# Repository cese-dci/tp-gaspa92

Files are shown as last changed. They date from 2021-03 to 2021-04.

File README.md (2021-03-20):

[][cc-by-sa]

This work is licensed under a
[Creative Commons Attribution-ShareAlike 4.0 International License][cc-by-sa].

[][cc-by-sa]

[cc-by-sa]: http://creativecommons.org/licenses/by-sa/4.0/
[cc-by-sa-image]: https://licensebuttons.net/l/by-sa/4.0/88x31.png
[cc-by-sa-shield]: https://img.shields.io/badge/License-CC%20BY--SA%204.0-lightgrey.svg

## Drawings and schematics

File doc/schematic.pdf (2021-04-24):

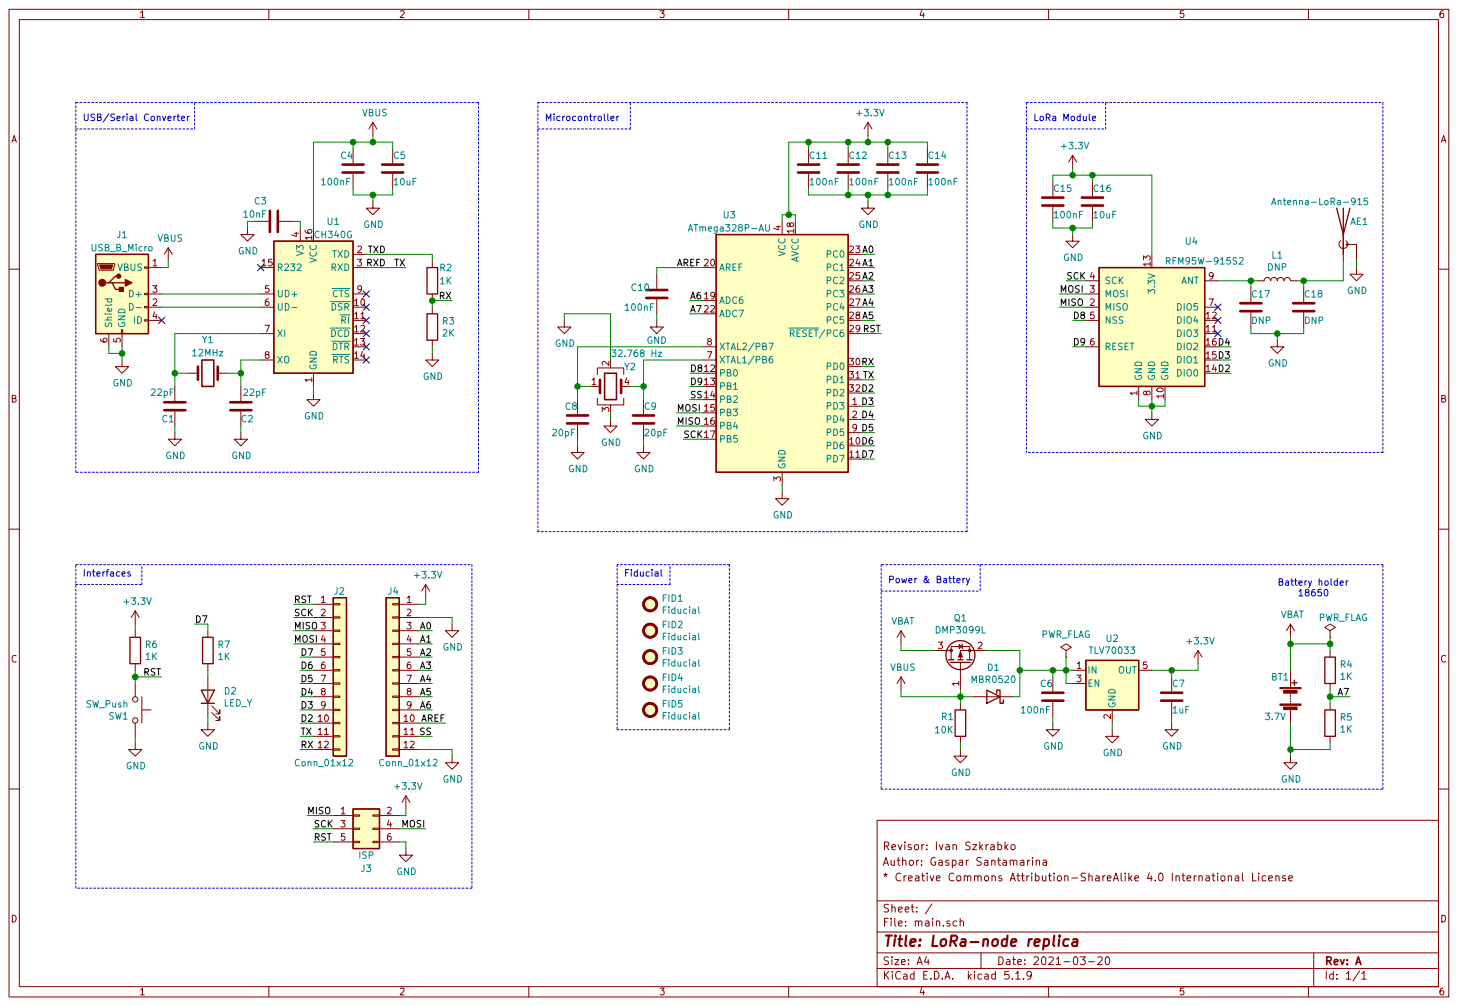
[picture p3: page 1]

4 UD+ 5 UD- 6 XI 7 XO 8 CTS 9 U1 CH340G

1 DSR 10 RI 11 DCD 12 DTR 13 RTS 14 R232 15 VCC 16 TXD 2 RXD 3 V3

1 GND 10 DIO3 11 DIO4 12 3.3V 13 DIO0 14 DIO1 15 DIO2 16 MISO 2 MOSI 3 SCK 4 NSS 5 RESET 6 DIO5 7 GND
SCK MOSI MISO

File: main.sch Sheet: / * Creative Commons Attribution-ShareAlike 4.0 International License Author: Gaspar Santamarina Revisor: Ivan Szkrabko

Id: 1/1 Title: LoRa-node replica

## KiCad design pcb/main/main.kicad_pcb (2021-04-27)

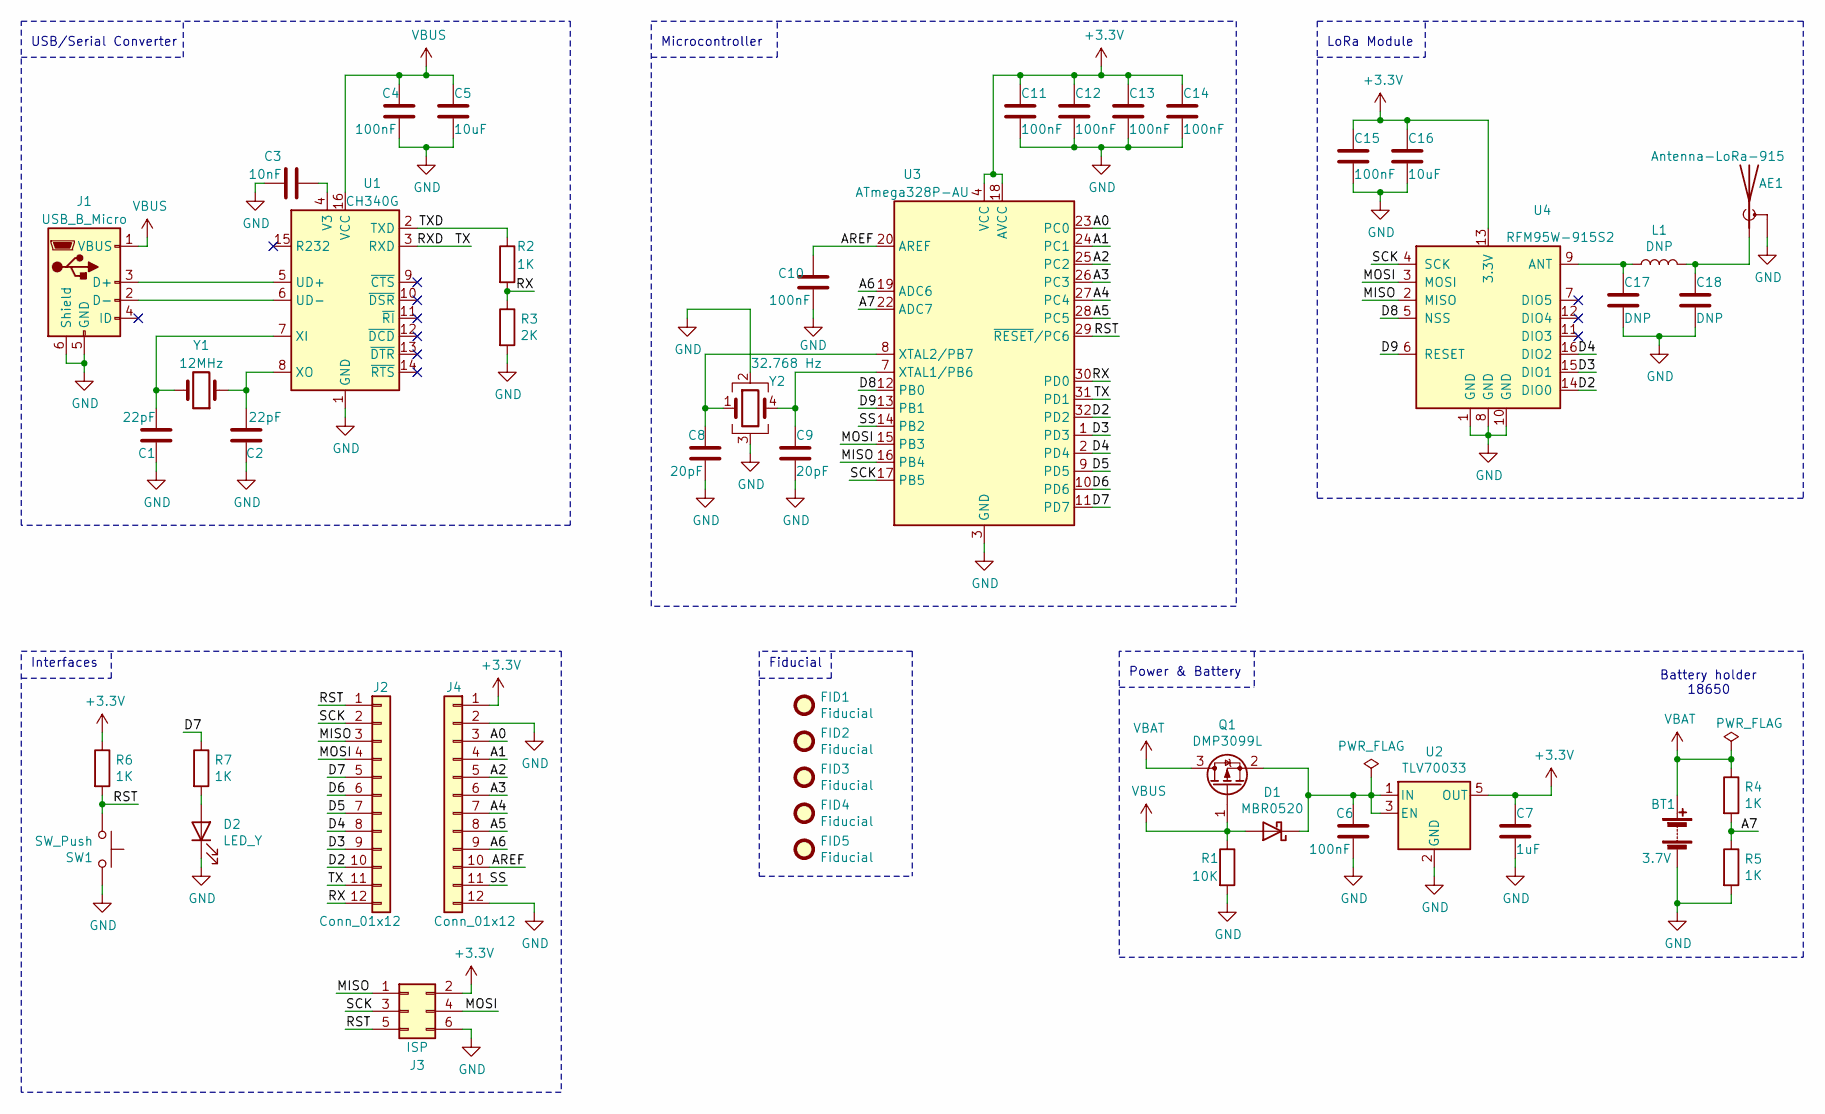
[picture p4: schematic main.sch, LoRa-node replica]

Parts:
AE1: Antenna-LoRa-915; antenna-lora-915
BT1: 3.7V; BatteryHolder_MPD_BH-18650-PC2; Digikey PN BH-18650-PC-ND
C1, C2: 22pF; C_0805_2012Metric_Pad1.18x1.45mm_HandSolder
C3: 10nF; C_0805_2012Metric_Pad1.18x1.45mm_HandSolder
C4, C6, C10, C11, C12, C13, C14, C15: 100nF; C_0805_2012Metric_Pad1.18x1.45mm_HandSolder
C5, C16: 10uF; C_0805_2012Metric_Pad1.18x1.45mm_HandSolder
C7: 1uF; C_0805_2012Metric_Pad1.18x1.45mm_HandSolder
C8, C9: 20pF; C_0805_2012Metric_Pad1.18x1.45mm_HandSolder
C17, C18: DNP; C_0805_2012Metric_Pad1.18x1.45mm_HandSolder
D1: MBR0520; D_SOD-123; Digikey PN MBR0520LT1GOSCT-ND
D2: LED_Y; LED_0805_2012Metric_Pad1.15x1.40mm_HandSolder
FID1, FID2, FID3, FID4, FID5: Fiducial; Fiducial_0.5mm_Mask1.5mm
J1: USB_B_Micro; USB_Micro-B_Molex_47346-0001; Digikey PN WM17141CT-ND
J2, J4: Conn_01x12; PinHeader_1x12_P2.54mm_Vertical
J3: ISP; PinHeader_2x03_P2.54mm_Vertical
L1: DNP; L_0805_2012Metric_Pad1.15x1.40mm_HandSolder
Q1: DMP3099L; SOT-23; Digikey PN DMP3099L-7DICT-ND
R1: 10K; R_0805_2012Metric_Pad1.20x1.40mm_HandSolder
R2, R4, R5, R6, R7: 1K; R_0805_2012Metric_Pad1.20x1.40mm_HandSolder
R3: 2K; R_0805_2012Metric_Pad1.20x1.40mm_HandSolder
SW1: SW_Push; SW_PUSH_6mm_H4.3mm
U1: CH340G; SOIC-16_3.9x9.9mm_P1.27mm
U2: TLV70033; SOT-23-5; Digikey PN 296-25276-1-ND
U3: ATmega328P-AU; TQFP-32_7x7mm_P0.8mm; Digikey PN ATMEGA328P-AU-ND
U4: RFM95W-915S2; HOPERF_RFM9XW_SMD
Y1: 12MHz; Crystal_SMD_HC49-SD; Digikey PN 1923-1541-1-ND
Y2: 32.768 Hz; Crystal_SMD_Abracon_ABS25-4Pin_8.0x3.8mm; Digikey PN 535-9166-1-ND

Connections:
+3V3: C7.1, C11.1, C12.1, C13.1, C14.1, C15.1, C16.1, J3.2, J4.1, R6.1, U2.5 (OUT), U3.4 (VCC), U3.6 (VCC), U3.18 (AVCC), U4.13 (3.3V)
/A0: J4.3, U3.23 (PC0)
/A1: J4.4, U3.24 (PC1)
/A2: J4.5, U3.25 (PC2)
/A3: J4.6, U3.26 (PC3)
/A4: J4.7, U3.27 (PC4)
/A5: J4.8, U3.28 (PC5)
/A6: J4.9, U3.19 (ADC6)
/A7: R4.2, R5.1, U3.22 (ADC7)
/AREF: C10.1, J4.10, U3.20 (AREF)
/D2: J2.10, U3.32 (PD2), U4.14 (DIO0)
/D3: J2.9, U3.1 (PD3), U4.15 (DIO1)
/D4: J2.8, U3.2 (PD4), U4.16 (DIO2)
/D5: J2.7, U3.9 (PD5)
/D6: J2.6, U3.10 (PD6)
/D7: J2.5, R7.1, U3.11 (PD7)
/D8: U3.12 (PB0), U4.5 (NSS)
/D9: U3.13 (PB1), U4.6 (RESET)
/MISO: J2.3, J3.1, U3.16 (PB4), U4.2 (MISO)
/MOSI: J2.4, J3.4, U3.15 (PB3), U4.3 (MOSI)
/RST: J2.1, J3.5, R6.2, SW1.1, U3.29 (~RESET~/PC6)
/RX: J2.12, R2.2, R3.1, U3.30 (PD0)
/RXD: J2.11, U1.3 (RXD), U3.31 (PD1)
/SCK: J2.2, J3.3, U3.17 (PB5), U4.4 (SCK)
/SS: J4.11, U3.14 (PB2)
/TXD: R2.1, U1.2 (TXD)
GND: AE1.2 (Shield), BT1.2 (-), C1.1, C2.1, C3.1, C4.2, C5.2, C6.2, C7.2, C8.2, C9.2, C10.2, C11.2, C12.2, C13.2, C14.2, C15.2, C16.2, C17.2, C18.2, D2.1 (K), J1.5 (GND), J1.6 (Shield), J3.6, J4.2, J4.12, R1.2, R3.2, R5.2, SW1.2, U1.1 (GND), U2.2 (GND), U3.3 (GND), U3.5 (GND), U3.21 (GND), U4.1 (GND), U4.8 (GND), U4.10 (GND), Y2.2, Y2.3
unnamed: AE1.1 (A), C18.1, L1.2
unnamed: C1.2, U1.7 (XI), Y1.2
unnamed: C2.2, U1.8 (XO), Y1.1
unnamed: C3.2, U1.4 (V3)
unnamed: C6.1, D1.1 (K), Q1.2 (S), U2.1 (IN), U2.3 (EN)
unnamed: C8.1, U3.8 (XTAL2/PB7), Y2.1
unnamed: C9.1, U3.7 (XTAL1/PB6), Y2.4
unnamed: C17.1, L1.1, U4.9 (ANT)
unnamed: D2.2 (A), R7.2
unnamed: J1.2 (D-), U1.6 (UD-)
unnamed: J1.3 (D+), U1.5 (UD+)
VBAT: BT1.1 (+), Q1.3 (D), R4.1
VBUS: C4.1, C5.1, D1.2 (A), J1.1 (VBUS), Q1.1 (G), R1.1, U1.16 (VCC)

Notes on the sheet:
Microcontroller
USB/Serial Converter
LoRa Module
Power & Battery
Interfaces
Battery holder 18650
Fiducial

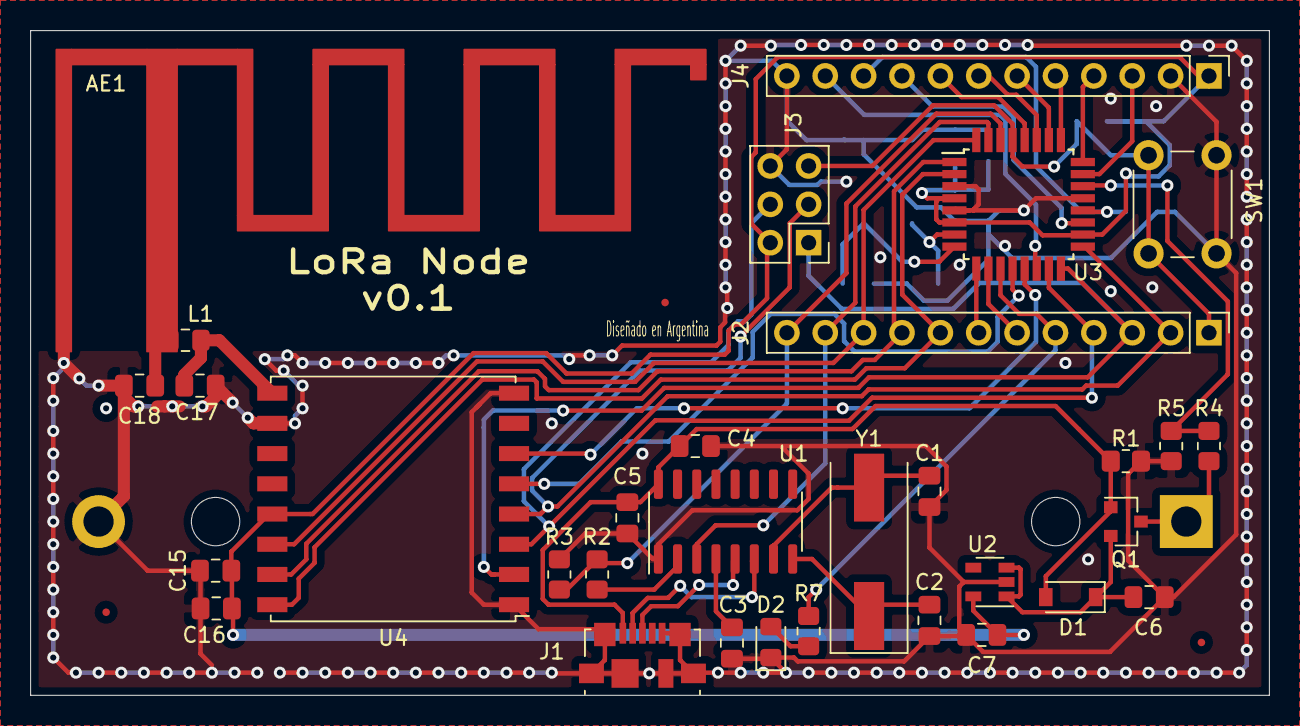
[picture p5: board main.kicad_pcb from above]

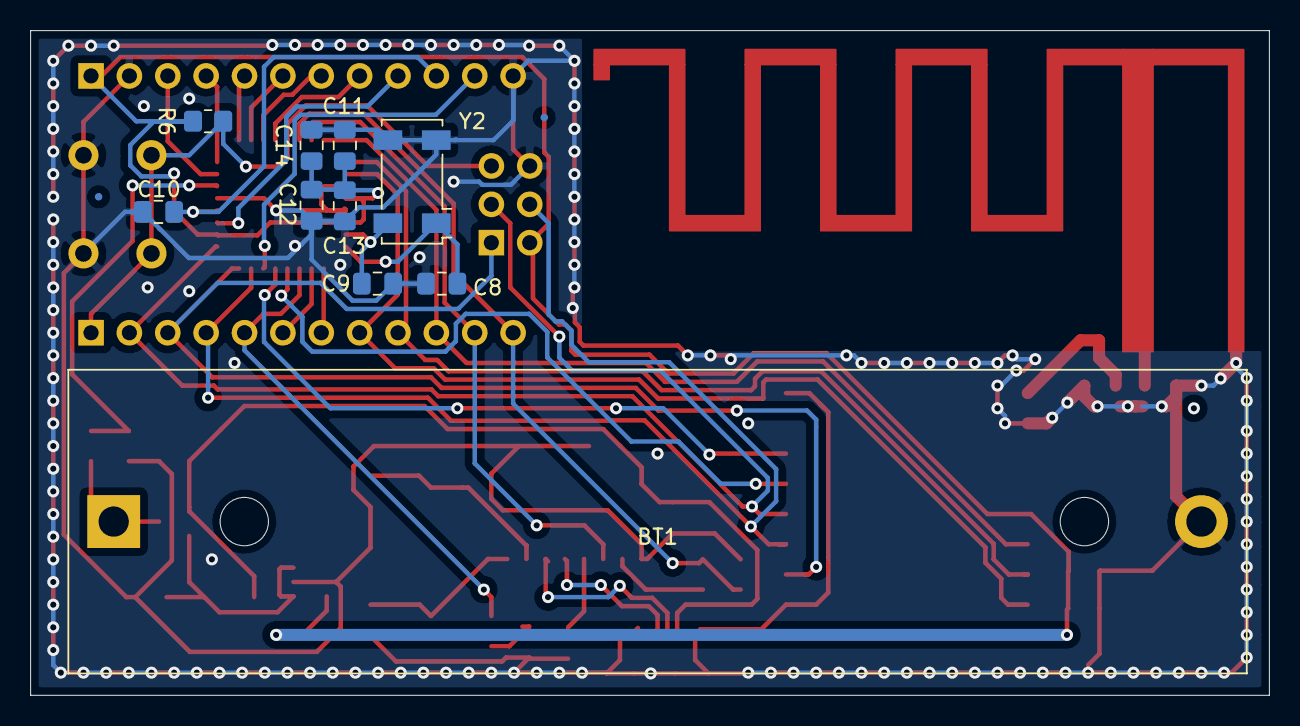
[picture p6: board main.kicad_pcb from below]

Board: 2 copper layers, 82.0 x 44.0 mm, 47 parts (12 on the bottom side), 40 nets.

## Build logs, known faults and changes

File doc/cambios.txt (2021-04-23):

- Agregar conversor Serie-USB CH340G
- Agregar prota batería y circuito de alimentación
- Agregar tira de pinas para tener acceso a los pines del microcontrolador

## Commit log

2021-03-18 Primer commit
    [main.kicad_pcb, main.sch]
2021-03-20 Added complete schematic
    [main.sch]
2021-03-20 Added schematic plot in PDF
2021-03-20 Minor fixes in schematic
    [main.sch]
2021-03-20 Update schematic plot
2021-03-20 Added DNP for antenna matching components values
    [main.sch]
2021-03-20 Schematic plot updated
2021-04-14 Footprints assigned
    [main.sch]
2021-04-15 Fix Rev field
    [main.sch]
2021-04-16 Added custom symbols lib
    [main.sch]
2021-04-17 Added antenna footprint
    [main.sch]
2021-04-17 Fix previous commit
    [main.sch]
2021-04-23 Fix - Correcciones solicitadas
    [main.sch]
2021-04-23 PCB added
    [main.kicad_pcb, main.sch]
2021-04-24 Fix fiducials and annotations
    [main.kicad_pcb, main.sch]

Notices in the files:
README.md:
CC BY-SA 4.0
